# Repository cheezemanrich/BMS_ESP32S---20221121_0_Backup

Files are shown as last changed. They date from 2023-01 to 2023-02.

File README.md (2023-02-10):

# BMS_ESP32S---20221121_0_Backup

NOTE: This is an As-Is rough prototype of software and hardware.
      It is in no way ready for release and has no guarantees.
      This is open source andyou are free to do with it as you like.

Project to communicate with Valence U27-12XP battery BMS module via RS485 using an ESP32 module.

Developed with VSCode and PlatformIO

Features:
    -Uses inexpensive ESP32-DevKitC module
    -Drives color LCD module over SPI
    -Built in web server to view near real time data
    -Configured for 4 parrallel and 2 series batteries (24V)
    -Cayenne MQTT
  
Note that this project can only compile under older Espressif 3.5.0 version.

Web page files need to uploaded to SPIFFS (Terminal menu > Run task.. > PlatformIO: Upload Filesystem Image)

There is a known bug that causes reboot due to a Watchdog triggered by the Com port driver.
This is supposedly fixed in later Espressif versions but I couldn't get it to compile and don't have the time to debug it.

Some of the info used to develop this came from the DIY Solar Power Forum:
  https://diysolarforum.com/threads/interfacing-with-valence-built-in-monitoring.2183/
  https://diysolarforum.com/threads/valence-xp-super-thread.5683/

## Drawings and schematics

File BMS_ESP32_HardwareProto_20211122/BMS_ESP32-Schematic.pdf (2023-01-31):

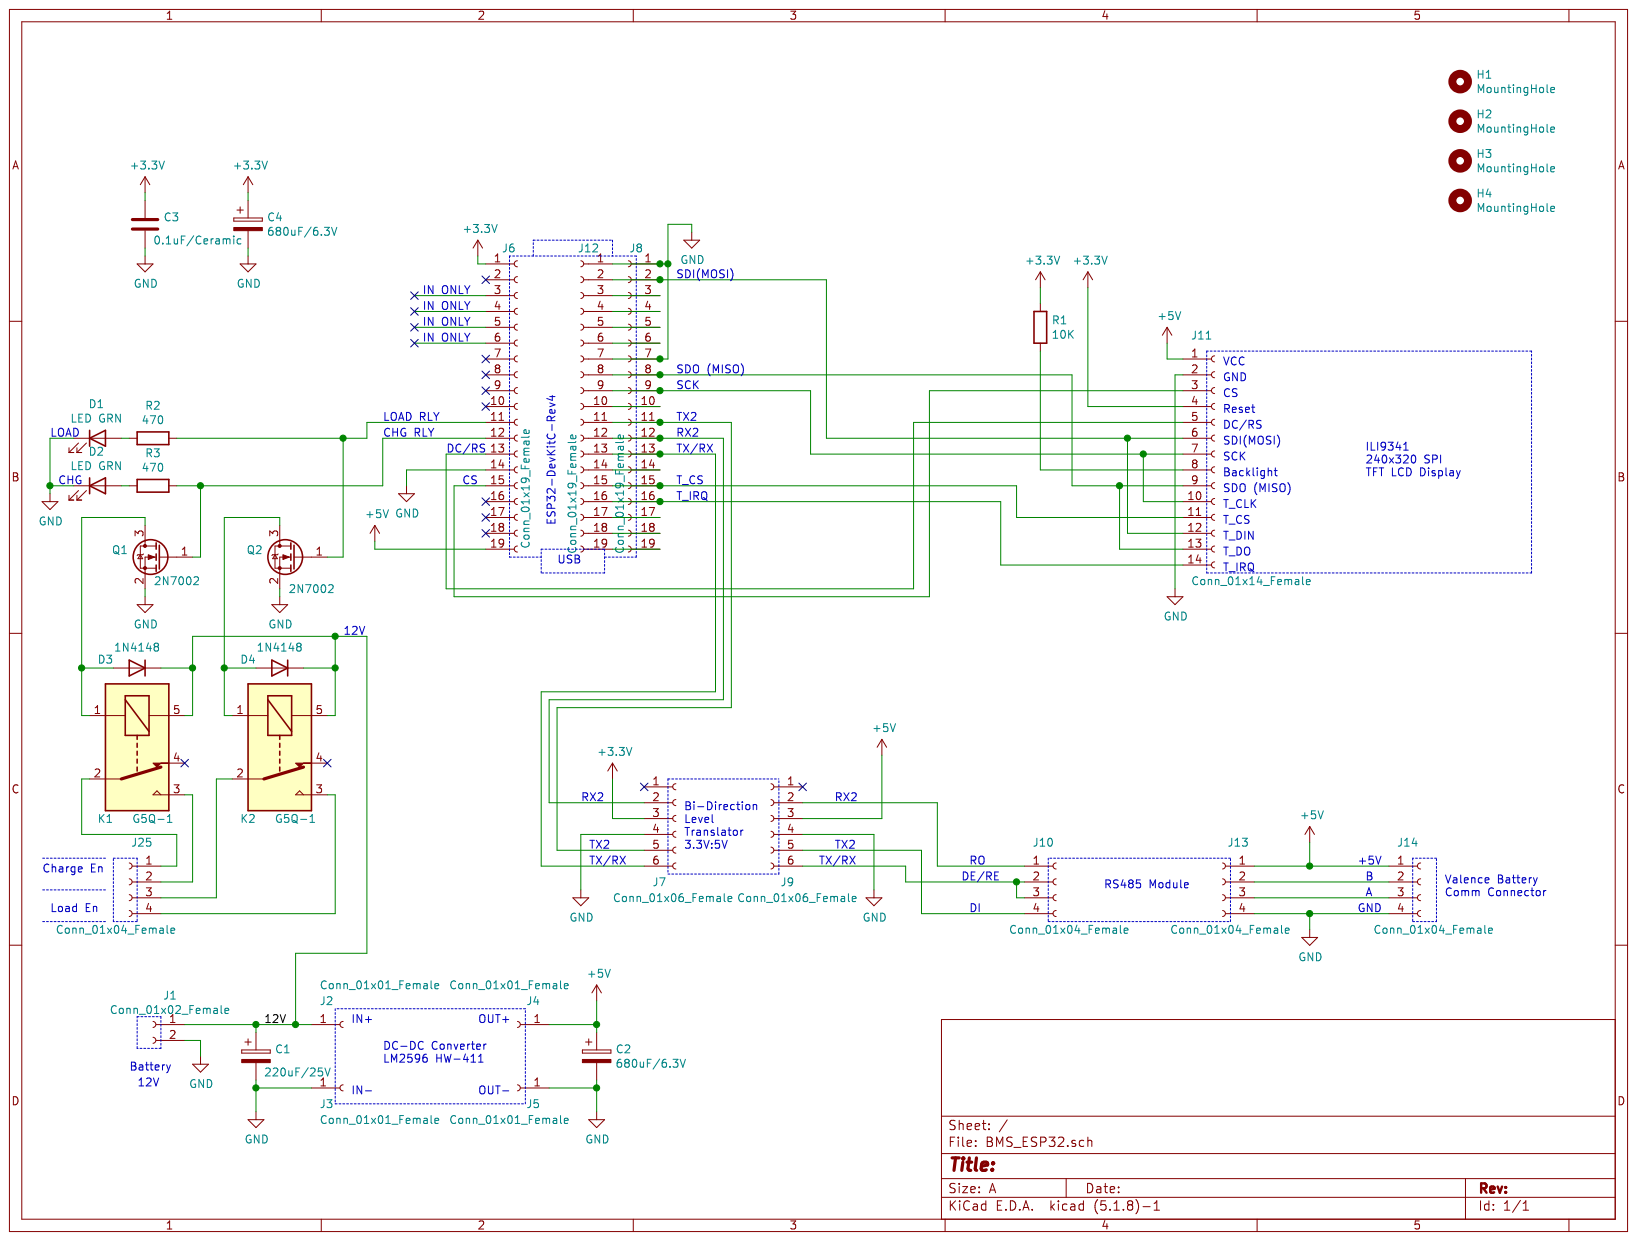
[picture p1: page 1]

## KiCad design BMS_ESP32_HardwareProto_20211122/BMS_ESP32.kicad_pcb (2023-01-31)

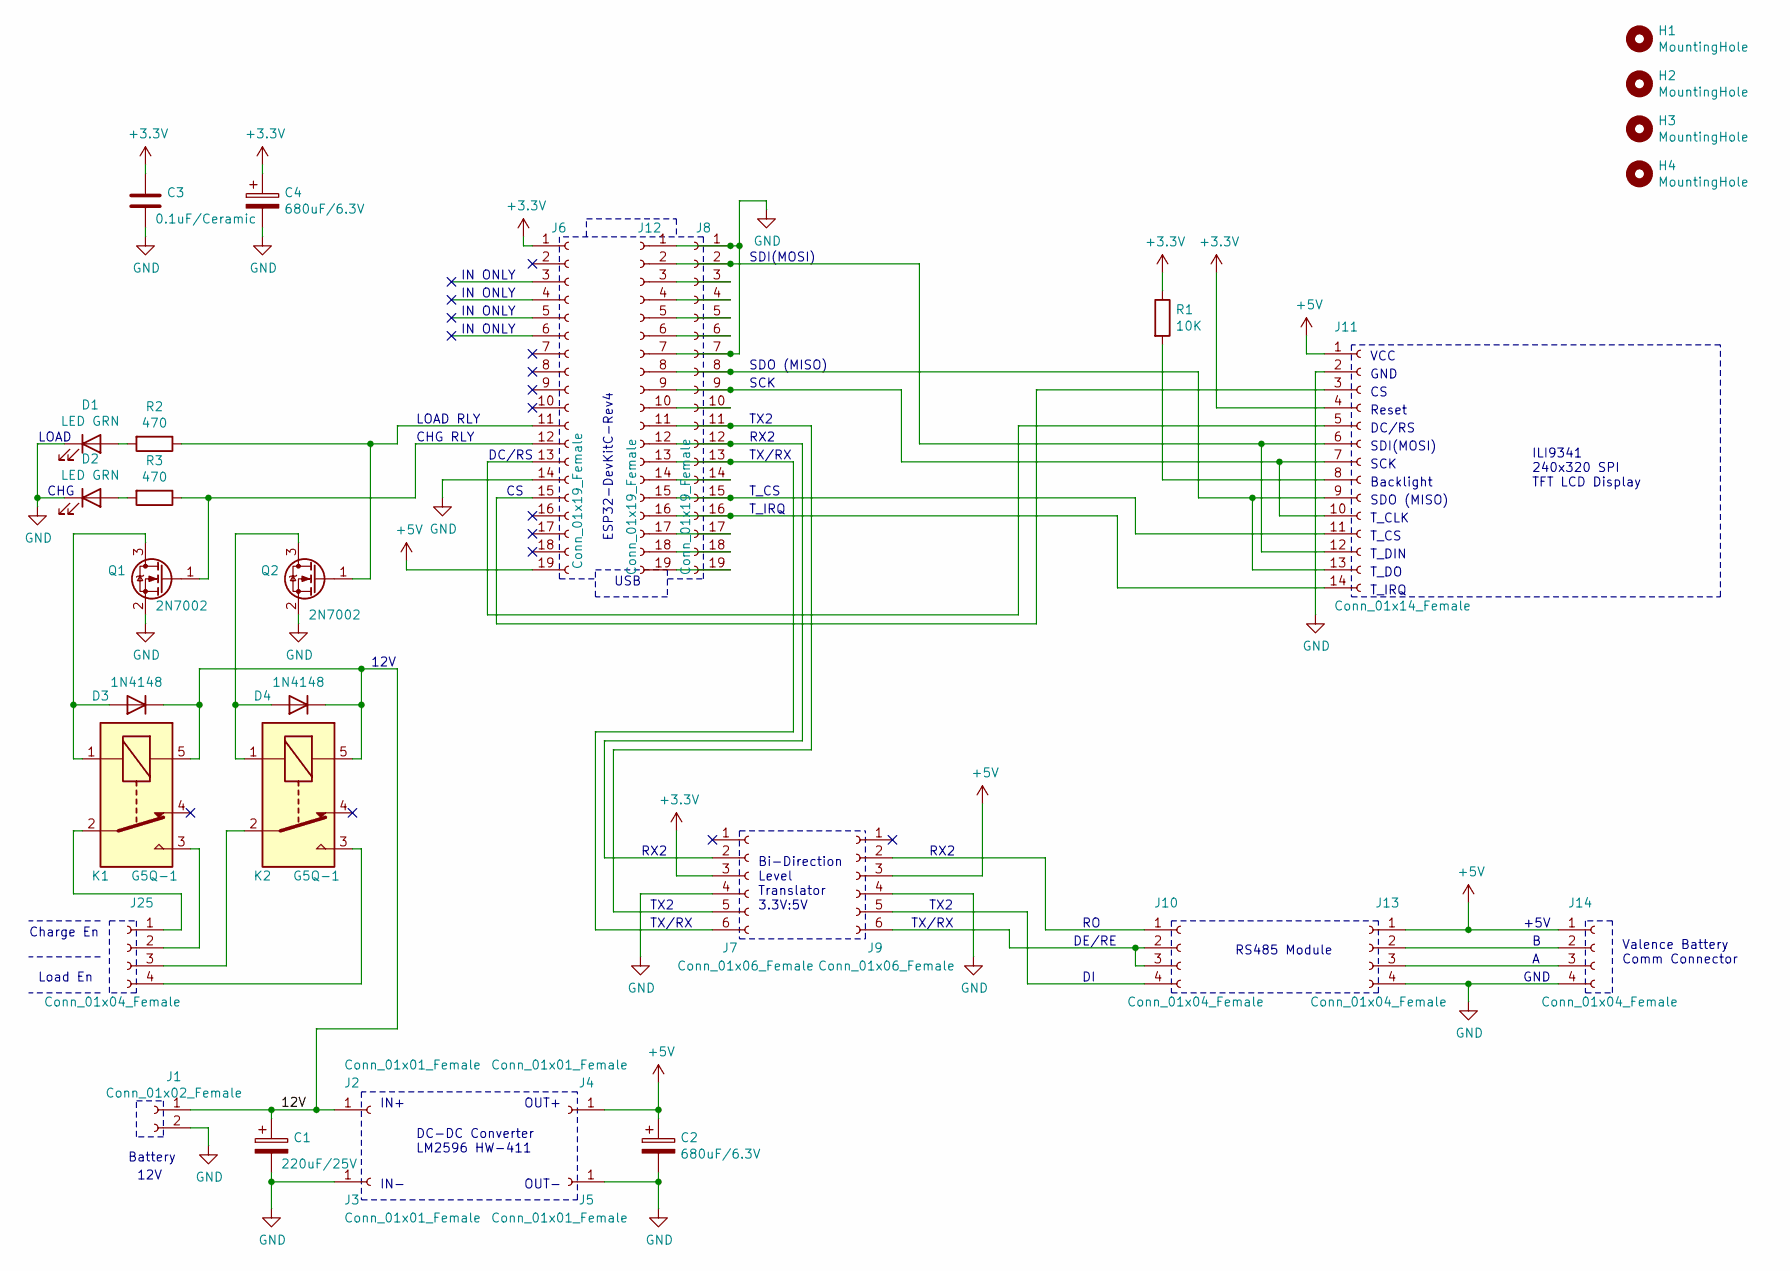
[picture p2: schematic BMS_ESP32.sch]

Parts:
C1: 220uF/25V; CP_Radial_D7.5mm_P2.50mm
C2, C4: 680uF/6.3V; CP_Radial_D7.5mm_P2.50mm
C3: 0.1uF/Ceramic; C_Rect_L7.0mm_W2.0mm_P5.00mm
D1, D2: LED GRN; LED_D5.0mm
D3, D4: 1N4148; D_DO-35_SOD27_P7.62mm_Horizontal
H1, H2, H3, H4: MountingHole; MountingHole_3.5mm
J1: Conn_01x02_Female; TerminalBlock_Phoenix_MKDS-1,5-2-5.08_1x02_P5.08mm_Horizont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
J2, J3, J4, J5: Conn_01x01_Female; PinSocket_1x01_P2.54mm_Vertical
J6, J8, J12: Conn_01x19_Female; PinSocket_1x19_P2.54mm_Vertical
J7, J9: Conn_01x06_Female; PinSocket_1x06_P2.54mm_Vertical
J10, J13: Conn_01x04_Female; PinSocket_1x04_P2.54mm_Vertical
J11: Conn_01x14_Female; PinSocket_1x14_P2.54mm_Vertical
J14, J25: Conn_01x04_Female; TerminalBlock_Phoenix_MKDS-1,5-4-5.08_1x04_P5.08mm_Horizont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
K1, K2: G5Q-1; Relay_SPDT_Omron-G5Q-1
Q1, Q2: 2N7002; SOT-23
R1: 10K; R_Axial_DIN0309_L9.0mm_D3.2mm_P12.70mm_Horizontal
R2, R3: 470; R_0805_2012Metric

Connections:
+3V3: C3.1, C4.1, J6.1, J7.3, J11.4, R1.1
+5V: C2.1, J4.1, J6.19, J9.3, J11.1, J13.1, J14.1
/12V: C1.1, D3.1 (K), D4.1 (K), J1.1, J2.1, K1.5, K2.5
GND: C1.2, C2.2, C3.2, C4.2, D1.1 (K), D2.1 (K), J1.2, J3.1, J5.1, J6.14, J7.4, J8.1, J8.7, J9.4, J11.2, J12.1, J12.7, J13.4, J14.4, Q1.2 (S), Q2.2 (S)
unnamed: D1.2 (A), R2.2
unnamed: D2.2 (A), R3.2
unnamed: D3.2 (A), K1.1, Q1.3 (D)
unnamed: D4.2 (A), K2.1, Q2.3 (D)
unnamed: J6.11, Q2.1 (G), R2.1
unnamed: J6.12, Q1.1 (G), R3.1
unnamed: J9.2, J10.1
unnamed: J9.6, J10.2, J10.3
unnamed: J9.5, J10.4
unnamed: J6.15, J11.3
unnamed: J6.13, J11.5
unnamed: J11.8, R1.2
unnamed: J8.9, J11.7, J11.10, J12.9
unnamed: J8.15, J11.11, J12.15
unnamed: J8.2, J11.6, J11.12, J12.2
unnamed: J8.8, J11.9, J11.13, J12.8
unnamed: J8.16, J11.14, J12.16
unnamed: J8.3, J12.3
unnamed: J8.4, J12.4
unnamed: J8.5, J12.5
unnamed: J8.6, J12.6
unnamed: J8.10, J12.10
unnamed: J7.5, J8.11, J12.11
unnamed: J7.2, J8.12, J12.12
unnamed: J7.6, J8.13, J12.13
unnamed: J8.14, J12.14
unnamed: J8.17, J12.17
unnamed: J8.18, J12.18
unnamed: J8.19, J12.19
unnamed: J13.2, J14.2
unnamed: J13.3, J14.3
unnamed: J25.1, K1.2
unnamed: J25.2, K1.3
unnamed: J25.3, K2.2
unnamed: J25.4, K2.3

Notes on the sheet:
Valence Battery Comm Connector
RS485 Module
ILI9341 240x320 SPI TFT LCD Display
DC-DC Converter LM2596 HW-411
IN+
IN-
OUT+
OUT-
Bi-Direction Level Translator 3.3V:5V
Battery
Reset
VCC
DC/RS
SDI(MOSI)
SCK
Backlight
SDO (MISO)
+5V
GND
DE/RE
RX2
TX2
TX/RX
Charge En
Load En
CHG RLY
LOAD RLY
CHG
LOAD
12V
ESP32-DevKitC-Rev4
IN ONLY
USB
T_CLK
T_CS
T_DIN
T_DO
T_IRQ

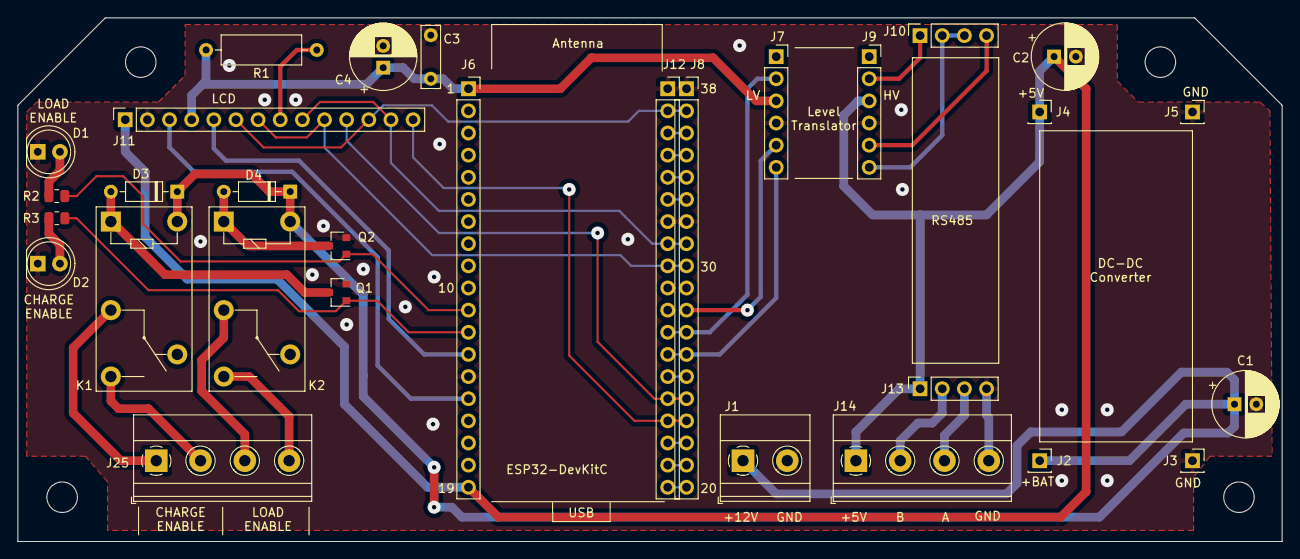
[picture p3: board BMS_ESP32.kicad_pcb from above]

Board: 2 copper layers, 145.0 x 60.1 mm, 34 parts (0 on the bottom side), 39 nets.

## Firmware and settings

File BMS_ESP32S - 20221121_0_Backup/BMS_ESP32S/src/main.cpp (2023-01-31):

//
// "ESP32 Dev Kit C V4" Version
// VS Code and PlatformIO version
//
// Current pinout:
// ******************************
// RS485 Board RO: GIOP16 (RX2) (Through 3.3V-5V logic translator)
// RS485 Board RE: GIOP4        (Through 3.3V-5V logic translator)
// RS485 Board DE: GIOP4        (Through 3.3V-5V logic translator)
// RS485 Board DI: GIOP17 (TX2) (Through 3.3V-5V logic translator)
// RS485 Board VCC: 5V and Battery Cable Pin 5
// RS485 Board GND: Gnd and Battery Cable Pin 2
// RS485 Board A: Battery Cable Pin 3
// RS485 Board B: Battery Cable Pin 4
// 
// Charge Enable Output: 14 (ON/OFF)
// Load Enable Output: 27 (ON/OFF)
// Charge Enable Output: 26 (PWM, 50% duty relay hold)
// Load Enable Output: 25 (PWM, 50% duty relay hold)
// 
// ILI9341 Pin 1: 5V
// ILI9341 Pin 2: Gnd
// ILI9341 Pin 3: GPIO13 (CS)
// ILI9341 Pin 4: 3.3V
// ILI9341 Pin 5: GPIO12 (DC)
// ILI9341 Pin 6: GPIO23 (MOSI/SDI)
// ILI9341 Pin 7: GPIO18 (SCK)
// ILI9341 Pin 8: 10k resistor to 3.3V (Backlight)
// ILI9341 Pin 9: GPIO19 (MISO/SDO)
// ILI9341 Pins 10-14 Not Used
//
// Debug timing pin: GPIO15
// 
// 
// Display and Console outputs setup as 4 parallel and 2 series batteries.
// Upper(+) battery IDs are 1,2,7,8
// Lower(-) battery IDs are 3,4,5,6
// 

#include "BMS_ESP32S.h"

// *****************************************
// Compute the MODBUS RTU CRC
// Adapted from https://ctlsys.com/support/how_to_compute_the_modbus_rtu_message_crc/
// This function MUST come before and other functions in the code if using Visual Studio Code and PlatformIO
// Not sure why but it will have compiling issues if placed anywhere else for some reason ¯\_(ツ)_/¯
// *****************************************
uint16_t ModRTU_CRC(unsigned char buf[], uint8_t len)
{
  uint16_t crc = 0xFFFF;
  
  for (int pos = 0; pos < len; pos++) {
    crc ^= buf[pos];          // XOR byte into least sig. byte of crc
    for (byte i = 8; i != 0; i--) {    // Loop over each bit
      if ((crc & 0x0001) != 0) {      // If the LSB is set
        crc >>= 1;                    // Shift right and XOR 0xA001
        crc ^= 0xA001;
      }
      else                            // Else LSB is not set
        crc >>= 1;                    // Just shift right
    }
  }
  // Note, this number has low and high bytes swapped, so use it accordingly (or swap bytes)
  return crc;  
};

// *****************************************
// Initialize startup operation
// *****************************************
void setup()
{
  // Make sure relays are "OFF" until BMS has received data from battery and determined it is safe to enable
  pinMode(loadRelay1, OUTPUT);
  pinMode(chargeRelay2, OUTPUT);
  digitalWrite(loadRelay1, OFF);
  digitalWrite(chargeRelay2, OFF);

  // Set RS485 TX/RX to receive
  pinMode(enablePin, OUTPUT);
  digitalWrite(enablePin, RECEIVE);

  // Set relay status to off on startup
  loadRelay1status = false;
  chargeRelay2status = false;

  // Initialize Relay PWM Channels with Frequency and Resolution
  ledcSetup(chargeRelayPWM_Channel, RelayPWM_Freq, RelayPWM_Resolution);
  ledcSetup(loadRelayPWM_Channel, RelayPWM_Freq, RelayPWM_Resolution);
  // Attach the Relay PWM Channel to the GPIO Pin
  ledcAttachPin(loadRelayPWMPIN, loadRelayPWM_Channel);
  ledcAttachPin(chargeRelayPWMPIN, chargeRelayPWM_Channel);
  // Load OFF duty cycle
  loadRelayDuty = 0;
  chargeRelayDuty = 0;
  
  // Setup debug timing pin for output only
  pinMode(debugTiming, OUTPUT);

  // Reset comm failure counter
  countFailures = 0;
  
  // Start console serial
  Serial.begin(115200);
  //Serial.println("Serial console started.");

  // Start bluetooth serial
  Serial1.begin(9600);
  //Serial.println("Serial 1 started. (Bluetooth?)");

  // start up the LCD and initialize it
  tft.begin();
  drawDisplayNew();

  //Start up the SPIFFS file system
  if(!SPIFFS.begin(true)){
    Serial.println("SPIFFS_ERROR");
    return;
  }

  // Connect to Wi-Fi network with SSID and password
  Serial.print("WiFi Connecting to: ");
  Serial.println(ssid);
  WiFi.begin(ssid, password);
  while (WiFi.status() != WL_CONNECTED) {
    delay(1000);
    Serial.print(".");
  }
  Serial.println(" ");
  Serial.print("Connected. IP: ");
  Serial.println(WiFi.localIP());

  // put the IP address on the display
  TFTTXTCYAN;
  charSetCursor(4, 39); // Positions are 0 referenced x, y
  tft.print(WiFi.localIP());

  // Web Server
  server.on("/", HTTP_GET, [](AsyncWebServerRequest *request){
    request->send(SPIFFS, "/index.html", "text/html");
  });

  server.on("/batt1.html", HTTP_GET, [](AsyncWebServerRequest *request){
    request->send(SPIFFS, "/batt1.html", "text/html");
  });

  server.on("/batt2.html", HTTP_GET, [](AsyncWebServerRequest *request){
    request->send(SPIFFS, "/batt2.html", "text/html");
  });

  server.on("/batt3.html", HTTP_GET, [](AsyncWebServerRequest *request){
    request->send(SPIFFS, "/batt3.html", "text/html");
  });

  server.on("/batt4.html", HTTP_GET, [](AsyncWebServerRequest *request){
    request->send(SPIFFS, "/batt4.html", "text/html");
  });

  server.on("/batt5.html", HTTP_GET, [](AsyncWebServerRequest *request){
    request->send(SPIFFS, "/batt5.html", "text/html");
  });

  server.on("/batt6.html", HTTP_GET, [](AsyncWebServerRequest *request){
    request->send(SPIFFS, "/batt6.html", "text/html");
  });

  server.on("/batt7.html", HTTP_GET, [](AsyncWebServerRequest *request){
    request->send(SPIFFS, "/batt7.html", "text/html");
  });

  server.on("/batt8.html", HTTP_GET, [](AsyncWebServerRequest *request){
    request->send(SPIFFS, "/batt8.html", "text/html");
  });

  server.on("/graph.html", HTTP_GET, [](AsyncWebServerRequest *request){
    request->send(SPIFFS, "/graph.html", "text/html");
  });

  server.on("/hist_data.xml", HTTP_GET, [](AsyncWebServerRequest *request){
    XML_hist_data(request);
  });
  
  server.serveStatic("/", SPIFFS, "/");

  // Request for the latest sensor readings
  server.on("/readings", HTTP_GET, [](AsyncWebServerRequest *request){
    String json = getBatteryReadings();
    request->send(200, "application/json", json);
    json = String();
  });

  events.onConnect([](AsyncEventSourceClient *client){
    if(client->lastId()){
      Serial.printf("Client reconnected! Last message ID that it got is: %u\n", client->lastId());
    }
    // send event with message "hello!", id current millis
    // and set reconnect delay to 1 second
    client->send("hello!", NULL, millis(), 10000);
  });

  server.addHandler(&events);
  server.begin();
  
  Serial.println("");

  Cayenne.begin(mqtt_username, mqtt_password, mqtt_clientID, ssid, password);
  Serial.println("Cayenne MQTT Started..");

  // wake up the batteries
  wakeup();

  // initialize all battery data to default -1 values (no comm)
  for (byte i = 0; i < sizeof(batteries); i++) {
    for (byte j = 0; j < BATTDATASIZE; j++) {
      battData[i][j] = -1;
    }
  }
}

// *****************************************
// Main loop
// *****************************************
void loop() {
  digitalWrite(debugTiming, ON); // Total loop time start pulse

  //WebSerial.println("Hello!"); // Test of the webserial terminal function

  startTime = millis();
  wakeup(); // Send the battery wakeup command

  // If the failure count gets too high, reset to 1 to prevent overflow.
  if (countFailures >=1){
    Serial.print("countFailures: ");
    Serial.println(countFailures);
  }
  if (countFailures >= 254) {
    countFailures = 1;
  }

  // Iterate through all of the batteries connected to the BMS.
  for (byte i = 0; i < sizeof(batteries) / sizeof(byte); i++) {
    requestBattVolts(i);
    delay(10);
    receiveBatteryVolts(i);

    requestBattTemps(i);
    delay(10);
    receiveBatteryTemps(i);

    requestBattCurrent(i);
    delay(10);
    receiveBatteryCurrent(i);

    requestBattBalance(i);
    delay(10);
    receiveBatteryBalance(i);

    requestBattSOC(i);
    delay(10);
    receiveBatterySOC(i);

  }

  // see if there were any flags for voltage or temperature
  checkBattStatus();

  // Calculate cell voltage delta for each battery and store it in VDELT location
  calcBattCellDelta();

  // Read status' and see if the relays should be enabled
  if (loadRelay1status) {
    relayWrite(loadRelay1, true);
  }
  if (chargeRelay2status) {
    relayWrite(chargeRelay2, true);
  }

  //clean out the buffer again, just in case there were more or less bytes
  while (Serial.available()) {
    Serial.read();
  }

  writeToDisplayNew(); // This function writes data to the LCD display
  //writeToDisplay(); // This function writes data to the LCD display

  //writeToConsole();

  getGraphReadings(); // get and store measurements to the graph array

  // Send Events to the web client with the Battery Readings
  events.send("ping",NULL,millis());
  events.send(getBatteryReadings().c_str(),"new_readings" ,millis());

  //Send UDP broadcast
  //udp.broadcast("Anyone here?");

  digitalWrite(debugTiming, OFF); //Total loop time end pulse

  //Cayenne.loop();

  currentTime = millis();
  while (currentTime - startTime < interval) {
    Cayenne.loop();
    // If everything runs at the fastest speed possible, we want to make sure there is
    // enough time between Serial1 messages when restarting the loop.
    currentTime = millis();
  }
}

// *****************************************
// Writes data to Cayenne MQTT
// *****************************************
CAYENNE_OUT_DEFAULT()
{
	// Write data to Cayenne here. This example just sends the current uptime in milliseconds on virtual channel 0.
	// Cayenne.virtualWrite(0, millis());
	// Some examples of other functions you can use to send data.
	//Cayenne.celsiusWrite(1, 22.0);
	//Cayenne.luxWrite(2, 700);
	//Cayenne.virtualWrite(3, 50, TYPE_PROXIMITY, UNIT_CENTIMETER);
  // Calculate total battery current - Average two parallel batts then add them as they are in series
  float BattVolt1 = battData[0][TOTAL];
  float BattVolt2 = battData[1][TOTAL];
  float BattVolt3 = battData[2][TOTAL];
  float BattVolt4 = battData[3][TOTAL];
  float BattVolt5 = battData[4][TOTAL];
  float BattVolt6 = battData[5][TOTAL];
  float BattVolt7 = battData[6][TOTAL];
  float BattVolt8 = battData[7][TOTAL];
  float BattCurr1 = battData[0][CURNT];
  float BattCurr2 = battData[1][CURNT];
  float BattCurr3 = battData[2][CURNT];
  float BattCurr4 = battData[3][CURNT];
  float BattCurr5 = battData[4][CURNT];
  float BattCurr6 = battData[5][CURNT];
  float BattCurr7 = battData[6][CURNT];
  float BattCurr8 = battData[7][CURNT];

  if (BattCurr1 > 32767) {
    BattCurr1 = BattCurr1 - 65535;
  }
  else {
    BattCurr1 = BattCurr1;
  }
  if (BattCurr2 > 32767) {
    BattCurr2 = BattCurr2 - 65535;
  }
  else {
    BattCurr2 = BattCurr2;
  }
  if (BattCurr3 > 32767) {
    BattCurr3 = BattCurr3 - 65535;
  }
  else {
    BattCurr3 = BattCurr3;
  }
  if (BattCurr4 > 32767) {
    BattCurr4 = BattCurr4 - 65535;
  }
  else {
    BattCurr4 = BattCurr4;
  }
  if (BattCurr5 > 32767) {
    BattCurr5 = BattCurr5 - 65535;
  }
  else {
    BattCurr5 = BattCurr5;
  }
  if (BattCurr6 > 32767) {
    BattCurr6 = BattCurr6 - 65535;
  }
  else {
    BattCurr6 = BattCurr6;
  }
  if (BattCurr7 > 32767) {
    BattCurr7 = BattCurr7 - 65535;
  }
  else {
    BattCurr7 = BattCurr7;
  }
  if (BattCurr8 > 32767) {
    BattCurr8 = BattCurr8 - 65535;
  }
  else {
    BattCurr8 = BattCurr8;
  }
  float totalBattVolt1 = ((BattVolt1 + BattVolt2 + BattVolt7 + BattVolt8) / 4) / 1000;
  float totalBattVolt2 = ((BattVolt3 + BattVolt4 + BattVolt5 + BattVolt6) / 4) / 1000;
  float totalBattVolt = (((BattVolt1 + BattVolt2 + BattVolt7 + BattVolt8) / 4) + ((BattVolt3 + BattVolt4 + BattVolt5 + BattVolt6) / 4)) / 1000;
  float totalBattCurr = (((BattCurr1 + BattCurr2 + BattCurr7 + BattCurr8) + (BattCurr3 + BattCurr4 + BattCurr5 + BattCurr6)) / 2) / 100;
  float totalBattWatt = ((((BattVolt1 + BattVolt2 + BattVolt7 + BattVolt8) / 4) + ((BattVolt3 + BattVolt4 + BattVolt5 + BattVolt6) / 4)) / 1000)
                      * ((((BattCurr1 + BattCurr2 + BattCurr7 + BattCurr8) + (BattCurr3 + BattCurr4 + BattCurr5 + BattCurr6)) /2) / 100);
  float totalSOC1 = battData[0][BTSOC];
  float totalSOC2 = battData[1][BTSOC];
  float totalSOC3 = battData[2][BTSOC];
  float totalSOC4 = battData[3][BTSOC];
  float totalSOC5 = battData[4][BTSOC];
  float totalSOC6 = battData[5][BTSOC];
  float totalSOC7 = battData[6][BTSOC];
  float totalSOC8 = battData[7][BTSOC];
  float totalSOC = ((((totalSOC1 + totalSOC2 + totalSOC5 + totalSOC6) / 4) + ((totalSOC3 + totalSOC4 + totalSOC7 + totalSOC8) / 4)) / 2) / 10;

  Cayenne.virtualWrite(0, totalSOC, "batt", "p");
  Cayenne.virtualWrite(1, totalBattWatt, "pow", "w");
  Cayenne.virtualWrite(2, totalBattCurr, "current", "a");
  Cayenne.virtualWrite(3, totalBattVolt, "voltage", "v");
  Cayenne.virtualWrite(4, totalBattVolt1, "voltage", "v");
  Cayenne.virtualWrite(5, totalBattVolt2, "voltage", "v");
  Cayenne.virtualWrite(11, battData[0][BALAN], "digital_sensor", "d");
  Cayenne.virtualWrite(12, battData[1][BALAN], "digital_sensor", "d");
  Cayenne.virtualWrite(13, battData[2][BALAN], "digital_sensor", "d");
  Cayenne.virtualWrite(14, battData[3][BALAN], "digital_sensor", "d");
  Cayenne.virtualWrite(15, battData[4][BALAN], "digital_sensor", "d");
  Cayenne.virtualWrite(16, battData[5][BALAN], "digital_sensor", "d");
  Cayenne.virtualWrite(17, battData[6][BALAN], "digital_sensor", "d");
  Cayenne.virtualWrite(18, battData[7][BALAN], "digital_sensor", "d");
  Serial.println("Cayenne MQTT Data Sent.");
}

// *****************************************
// Writes data to SPI LCD
// *****************************************
void drawDisplayNew() {
  TFTSCRBLACK;
  TFTTXTGREEN;
  tft.setTextSize(1);
  tft.setCursor(0, 0);

  TFTTXTWHITE;
  tft.print("      Cel1:Cel2:Cel3:Cel4:Total\r\n"); // Y=0
  tft.print("Batt1:    :    :    :    :     \r\n"); // X pos starts at : which is 5
  tft.print("Batt2:    :    :    :    :     \r\n");
  tft.print("Batt3:    :    :    :    :     \r\n");
  tft.print("Batt4:    :    :    :    :     \r\n");
  tft.print("Batt5:    :    :    :    :     \r\n");
  tft.print("Batt6:    :    :    :    :     \r\n");
  tft.print("Batt7:    :    :    :    :     \r\n");
  tft.print("Batt8:    :    :    :    :     \r\n");
  tft.print(" \r\n");
  tft.print("      Tmp1:Tmp2:Tmp3:Tmp4:Tmp5 \r\n"); // Y=10
  tft.print("Batt1:    :    :    :    :     \r\n"); // X pos starts at : which is 5
  tft.print("Batt2:    :    :    :    :     \r\n");
  tft.print("Batt3:    :    :    :    :     \r\n");
  tft.print("Batt4:    :    :    :    :     \r\n");
  tft.print("Batt5:    :    :    :    :     \r\n");
  tft.print("Batt6:    :    :    :    :     \r\n");
  tft.print("Batt7:    :    :    :    :     \r\n");
  tft.print("Batt8:    :    :    :    :     \r\n");
  tft.print(" \r\n");
  tft.print("      V:T:Curr:Bal:SOC :Delta \r\n");  // Y=20
  tft.print("Batt1: : :    :   :    :     \r\n"); // X pos starts at : which is 5
  tft.print("Batt2: : :    :   :    :     \r\n");
  tft.print("Batt3: : :    :   :    :     \r\n");
  tft.print("Batt4: : :    :   :    :     \r\n");
  tft.print("Batt5: : :    :   :    :     \r\n");
  tft.print("Batt6: : :    :   :    :     \r\n");
  tft.print("Batt7: : :    :   :    :     \r\n");
  tft.print("Batt8: : :    :   :    :     \r\n");
  tft.print(" \r\n");
  tft.print("Upr:            Lwr:       \r\n");  // Y=30, X=5 and X=21
  tft.print("Vlt:            Cur:       \r\n");  // Y=31, X=5 and X=21
  tft.setTextSize(2);
  tft.print("                      \r\n"); // Location of Power
  tft.print("SOC:    \r\n");
  tft.setTextSize(1);
  tft.print("LoadRelay:      ChrgRelay:   \r\n");  // Y=37, X=11 and X=27
  tft.print("IP:               \r\n");  // Y=38, X=4
}
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

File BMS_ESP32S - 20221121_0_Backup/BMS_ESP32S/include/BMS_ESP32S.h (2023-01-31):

//
// "ESP32 Dev Kit C V4" Version
// VS Code and PlatformIO version
//
// Current pinout:
// ******************************
// RS485 Board RO: GIOP16 (RX2) (Through 3.3V-5V logic translator)
// RS485 Board RE: GIOP4        (Through 3.3V-5V logic translator)
// RS485 Board DE: GIOP4        (Through 3.3V-5V logic translator)
// RS485 Board DI: GIOP17 (TX2) (Through 3.3V-5V logic translator)
// RS485 Board VCC: 5V and Battery Cable Pin 5
// RS485 Board GND: Gnd and Battery Cable Pin 2
// RS485 Board A: Battery Cable Pin 3
// RS485 Board B: Battery Cable Pin 4
// 
// Charge Enable Output: 14 (ON/OFF)
// Load Enable Output: 27 (ON/OFF)
// Charge Enable Output: 26 (PWM, 50% duty relay hold)
// Load Enable Output: 25 (PWM, 50% duty relay hold)
// 
// ILI9341 Pin 1: 5V
// ILI9341 Pin 2: Gnd
// ILI9341 Pin 3: GPIO13 (CS)
// ILI9341 Pin 4: 3.3V
// ILI9341 Pin 5: GPIO12 (DC)
// ILI9341 Pin 6: GPIO23 (MOSI/SDI)
// ILI9341 Pin 7: GPIO18 (SCK)
// ILI9341 Pin 8: 10k resistor to 3.3V (Backlight)
// ILI9341 Pin 9: GPIO19 (MISO/SDO)
// ILI9341 Pins 10-14 Not Used
//
// Debug timing pin: GPIO15
// 

#include <Arduino.h>
#include <Wire.h>
#include <SPI.h>
#include <Adafruit_GFX.h>
#include <Adafruit_ILI9341.h>
#include <WiFi.h>
#include <ESPAsyncWebServer.h>
#include <Arduino_JSON.h>
#include <SPIFFS.h>
#include <CayenneMQTTESP32.h>

// Replace with your network credentials
const char* ssid = "Your WiFi SSID";
const char* password = "Your WiFi Password";

//Cayenne MQTT Info
char mqtt_username[] = "Your MQTT Info";
char mqtt_password[] = "Your MQTT Info";
char mqtt_clientID[] = "Your MQTT Info";

// Set web server port number to 80
AsyncWebServer server(80);

// Create an Event Source on /events
AsyncEventSource events("/events");

// Json Variable to Hold Sensor Readings
JSONVar readings;

// Number of points in the graphing XML file
#define N_POINTS 240

// fancy math to find out how often to sample chart
#define DIVIDER_HIST ((48*60*1000)/N_POINTS/(1000))*60

uint16_t index_counter = 0;
uint16_t count = DIVIDER_HIST;

enum State { XML_Preamble, XML_Body, XML_Done };

// Data items for graphing
struct btData{
  float batt1volt1[N_POINTS];
  float batt1volt2[N_POINTS];
  float batt1volt3[N_POINTS];
  float batt1volt4[N_POINTS];
  float batt2volt1[N_POINTS];
  float batt2volt2[N_POINTS];
  float batt2volt3[N_POINTS];
  float batt2volt4[N_POINTS];
  float batt3volt1[N_POINTS];
  float batt3volt2[N_POINTS];
  float batt3volt3[N_POINTS];
  float batt3volt4[N_POINTS];
  float batt4volt1[N_POINTS];
  float batt4volt2[N_POINTS];
  float batt4volt3[N_POINTS];
  float batt4volt4[N_POINTS];
  float batt5volt1[N_POINTS];
  float batt5volt2[N_POINTS];
  float batt5volt3[N_POINTS];
  float batt5volt4[N_POINTS];
  float batt6volt1[N_POINTS];
  float batt6volt2[N_POINTS];
  float batt6volt3[N_POINTS];
  float batt6volt4[N_POINTS];
  float batt7volt1[N_POINTS];
  float batt7volt2[N_POINTS];
  float batt7volt3[N_POINTS];
  float batt7volt4[N_POINTS];
  float batt8volt1[N_POINTS];
  float batt8volt2[N_POINTS];
  float batt8volt3[N_POINTS];
  float batt8volt4[N_POINTS];
};

struct powerData{
  btData bt;
  unsigned long time[N_POINTS];
  bool valid[N_POINTS] = {};
};

struct powerData p_data;

// For the ILI9341, these are the default pins.
#define TFT_MISO 19
#define TFT_MOSI 23
#define TFT_SCLK 18
#define TFT_DC  32
#define TFT_CS 33
// Use hardware SPI (#13, #12, #11) and the above for CS/DC
Adafruit_ILI9341 tft = Adafruit_ILI9341(TFT_CS, TFT_DC);

// Set digital out pin numbers for relays. loadRelay1 is the load disconnect and chargeRelay2 is a charge disconnect.
#define loadRelay1 27
#define chargeRelay2 14

// PWM variables for relay hold function
const int loadRelayPWMPIN = 25;
const int chargeRelayPWMPIN = 26;
const int RelayPWM_START = 255;
const int RelayPWM_ON = 128;
const int chargeRelayPWM_Channel = 0;
const int loadRelayPWM_Channel = 2;
const int RelayPWM_Freq = 20000;
const int RelayPWM_Resolution = 8;
const int RelayPWM_MAXDUTY = (int)(pow(2, RelayPWM_Resolution) - 1);
uint16_t loadRelayDuty;
uint16_t chargeRelayDuty;

#define enablePin 4 // Pin used to switch RS485 TX/RX - High=TX, Low=RX

#define debugTiming 15 // Pin used for analyzing during scope debugging timing or path issues

#define RECEIVE LOW // RS485 Pin Mode
#define TRANSMIT HIGH //RS485 Pin Mode
#define OFF LOW // Relay Pin Mode
#define ON HIGH // Relay Pin Mode

// Used for formatting console to binary display of integers
// Use: printf("Leading text "BYTE_TO_BINARY_PATTERN, BYTE_TO_BINARY(byte));
#define BYTE_TO_BINARY_PATTERN "%c%c%c%c%c%c%c%c"
#define BYTE_TO_BINARY(byte)  \
  (byte & 0x80 ? '1' : '0'), \
  (byte & 0x40 ? '1' : '0'), \
  (byte & 0x20 ? '1' : '0'), \
  (byte & 0x10 ? '1' : '0'), \
  (byte & 0x08 ? '1' : '0'), \
  (byte & 0x04 ? '1' : '0'), \
  (byte & 0x02 ? '1' : '0'), \
  (byte & 0x01 ? '1' : '0')

// Set BMS thresholds - mV and C
int battHighV = 3600;  // 3600 Default
int battLowV = 2750;  // 2750 Default
int battHighT = 6000;  // 6000 Default
int battLowT = 0200;  // 0200 Default

// keeps track of display update task state
uint8_t displayUpdateState = 0;

// The loop will change one or both of these depending on the data from the batteries.
bool loadRelay1status = true;
bool chargeRelay2status = true;

// Wake UP (9600 baud) must be used to keep the batteries awake to communicate
byte messageW[] =    {0x00, 0x00, 0x01, 0x01, 0xc0, 0x74, 0x0d, 0x0a, 0x00, 0x00};

// Commands to send to the batteries. (115200 baud) MODBUS
//                    ID  , Func, HReg, LReg, HLen, LLen, HCRC, LCRC, End , End
byte readVolts[] =   {0x00, 0x03, 0x00, 0x45, 0x00, 0x09, 0x00, 0x00, 0x0d, 0x0a};
byte readTemps[] =   {0x00, 0x03, 0x00, 0x50, 0x00, 0x07, 0x00, 0x00, 0x0d, 0x0a};
byte readCurrent[] = {0x00, 0x03, 0x00, 0x39, 0x00, 0x0a, 0x00, 0x00, 0x0d, 0x0a};
byte readBalance[] = {0x00, 0x03, 0x00, 0x1e, 0x00, 0x01, 0x00, 0x00, 0x0d, 0x0a};
byte readSOC[] =     {0x00, 0x03, 0x00, 0x6a, 0x00, 0x0c, 0x00, 0x00, 0x0d, 0x0a};

unsigned long startTime;  // Time tracking for the poll loop
unsigned long currentTime;  // Time tracking for the poll loop
unsigned long interval = 1000;  // How often to poll the batteries in milliseconds
unsigned int countFailures = 0; // Keeps track of how many times the battery didn't have a valid response

// Set address numbers for batteries you want to communicate
byte batteries[] = {0x01, 0x02, 0x03, 0x04, 0x05, 0x06, 0x07, 0x08};
// Display and Console outputs setup as 4 parallel and 2 series batteries.
// Upper (positive side) battery IDs are 1,2,7,8
// Lower (negative side) battery IDs are 3,4,5,6

// Array for each battery
#define BATTDATASIZE 16
int battData[sizeof(batteries)][BATTDATASIZE];
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
